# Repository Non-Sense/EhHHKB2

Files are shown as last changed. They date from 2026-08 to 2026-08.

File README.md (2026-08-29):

# EhHHKB2

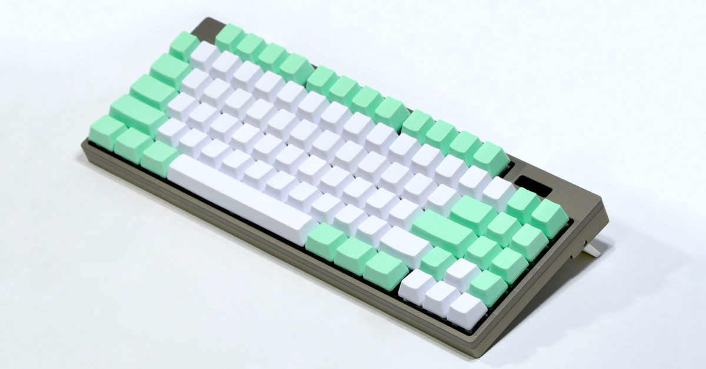
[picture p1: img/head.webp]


[ブログ記事](https://blog.n0n5ense.com/blog/DcFo77JwRCHzNenNpN4wraU0PMD/)

Raspberry Pi Pico 2 W（RP2350 + CYW43）を載せた自作キーボード。
85 キー（8×11 マトリクス / 6 行）、USB HID と BLE HID の両対応で、
BLE は6ホストを記憶して切り替えられる。128x32 OLED で状態表示と設定操作ができる。

## ディレクトリ

| ディレクトリ | 内容 |
| --- | --- |
| `board/` | KiCad 10 のプロジェクト一式（回路図・PCB・プロジェクト専用ライブラリ） |
| `case/` | ケースの 3D データ（STEP）とレンダー画像 |
| `firmware/` | Pico SDK ベースのファームウェア（C）、ホスト単体テスト、ドキュメント生成スクリプト |

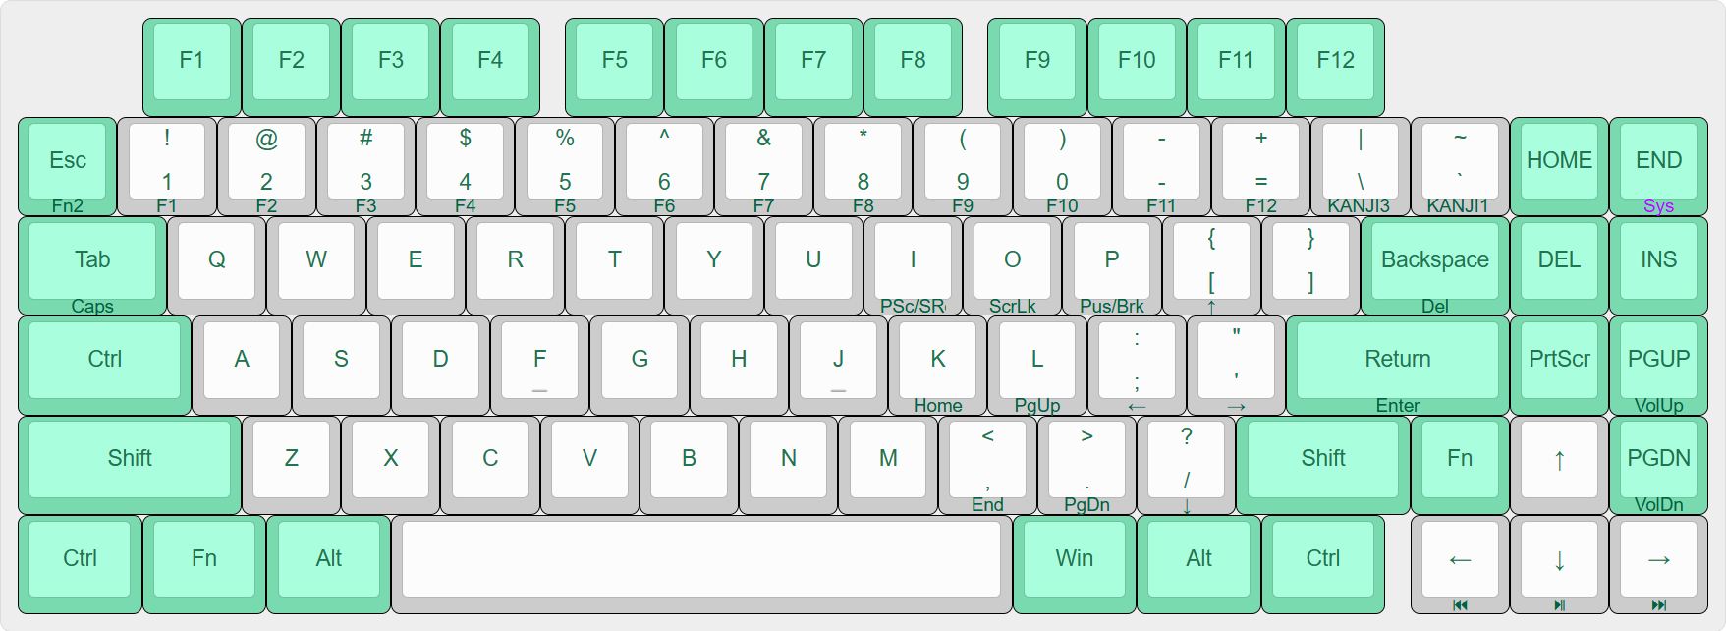
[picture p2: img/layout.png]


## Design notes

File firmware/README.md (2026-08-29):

# EhHHKB2 Firmware

Raspberry Pi Pico 2 W（RP2350 + CYW43）向けの自作キーボードファームウェア。
USB HID と BLE HID（HID over GATT）の両対応で、BLE は 6 ホストを記憶して切り替えられる。
128x32 の OLED に接続状態・バッテリー・LED インジケータを表示し、キーボードだけで設定変更ができる。

## 主な機能

- 8×11 キーマトリクス（88 交点のうち 85 キー）、0.5ms 周期スキャン・押下優先デバウンス
- 3 レイヤー（`_BASE` / `_FN` / `_FN2`）。押下した瞬間のキーコードをラッチするので、
  修飾を先に離してもキーが化けない
- 128bit bitmap レポートによる NKRO。ホストが Boot Protocol を要求したら 6KRO へ自動フォールバック
- Consumer Control による メディアキー（音量・再生・曲送り等）。USB / BLE 両対応
- BLE ホストスロット 6 個。ボンド・スロット名・Mac モードをフラッシュに永続化し、ホワイトリスト広告で切り替える
- スロットごとの Mac モード（`Ctrl` と `GUI(Win)` の usage を入れ替えて送信する）
- 出力先は「最後に接続が確立した方」のみ。USB と BLE へ同時送信はしない
- SSD1306 OLED への状態表示と、キーボードから操作するコンフィグメニュー
- バッテリー電圧の ADC 監視と、バッテリー駆動時の自動消灯

## ハードウェア

| 機能 | GPIO |
| --- | --- |
| キーマトリクス row（入力・プルアップ） | 2–9 |
| キーマトリクス col（出力・スキャン時のみ LOW） | 10–20 |
| OLED I2C0 SDA | 0 |
| OLED I2C0 SCL | 1 |
| USB センス（初期化のみ・未使用） | 22 |
| バッテリー電圧（ADC2 / 1/2 分圧） | 28 |

- ボード: `pico2_w`
- OLED: SSD1306 128x32、I2C アドレス `0x3C`、400kHz
- stdio（UART / USB CDC）は無効

## ビルド

Pico SDK 2.2.0 と arm toolchain 14_2_Rel1 を前提にしている（`~/.pico-sdk` 配下、または `PICO_SDK_PATH`）。

```powershell
cmake -S . -B build
cmake --build build
```

生成物は `build/ehhhkb2.uf2`。BOOTSEL を押しながら接続してドラッグ&ドロップするか、
コンフィグメニューの `Boot mode` から書き込みモードへ再起動できる。

### ホスト単体テスト

ハードウェアに触れないロジック（`ui/config_menu.c` と `hid/hid_report.c`）は PC 上で実行できる。

```powershell
cmake -S tests -B build-tests
cmake --build build-tests
ctest --test-dir build-tests --output-on-failure
```

### ドキュメント生成

`scripts/` に、OLED の全画面を実機と同じピクセル配置で PNG 化し、それを埋め込んだ
メニュー操作ガイド（`scripts/out/manual.html`、1 枚の自己完結 HTML）を組み立てる
スクリプトがある。`render_screens.py` は `display/ssd1306.c` の `font_data[]` と
`ui/screen.c` の描画ロジックを Python へ移植したものなので、**フォントや画面描画・
メニュー構成を変えたら両方を追従させて再生成する。**

```powershell
python -m venv scripts/.venv
scripts/.venv/Scripts/python.exe -m pip install -r scripts/requirements.txt
scripts/.venv/Scripts/python.exe scripts/render_screens.py   # scripts/out/*.png
scripts/.venv/Scripts/python.exe scripts/build_manual.py     # scripts/out/manual.html
```

## キーマップ

配列定義は `hid/key_matrix.c` の `keymap`、物理配列と行列の対応は `hid/key_matrix.h` の `LAYOUT` マクロ。

`_FN` は FN キー（右 Shift 隣 / 左下）の押下中、`_FN2` は FN + Esc の押下中に有効になる。
透過キーは `_FN2` → `_FN` → `_BASE` の順にフォールスルーする。

### `_FN`（FN 押下中）

| 押すキー | 出力 |
| --- | --- |
| `1`–`0` / `-` / `=` | F1–F10 / F11 / F12 |
| `` ` `` / `\` | Delete / Insert |
| `Tab` | CapsLock |
| `I` / `O` / `P` | PrintScreen / ScrollLock / Pause |
| `[` / `;` / `'` / `/` | ↑ / ← / → / ↓ |
| `K` / `,` / `L` / `.` | Home / End / PageUp / PageDown |
| `PageUp` / `PageDown` | 音量アップ / 音量ダウン（メディアキー） |
| `Esc` | `_FN2` レイヤーへ |

### `_FN2`（FN + Esc 押下中）

| 押すキー | 動作 |
| --- | --- |
| `1`–`6` | BLE スロット `BT1`–`BT6` へ接続を切り替える |
| `7` | BT を無効化して USB 専用にする |
| `Space` | ペアリング開始（オープン広告で新規デバイスを待つ）。ペアリング中に押すと離脱する |
| `Z` | 全スロットのボンドと名前を削除して待機 |
| `End` | コンフィグメニューを開く |

## BLE

- 広告名 `EhHHKB2` / Appearance `0x03C1`（キーボード） / HID Service `0x1812`
- ペアリングは Just Works（`IO_CAPABILITY_NO_INPUT_NO_OUTPUT`、Secure Connections + Bonding）
- Battery Service は実測電圧を Li-Po の放電曲線で 0–100% に換算して通知する。
  値が変わったときだけ、かつ 60 秒以上の間隔をおいて送る
- スロット番号は `le_device_db` のインデックスに直結する。上限は 6（`MAX_NR_LE_DEVICE_DB_ENTRIES` / `BLE_HOST_SLOTS`）
- スロット名（最大 10 文字）は BTstack の TLV フラッシュに保存される

### ホスト切り替えの挙動

対象スロットのボンドをホワイトリストに載せて広告することで、直前まで接続していたホスト OS の
即時再接続を弾いている。RPA を使うホストでも、コントローラのリゾルビングリストへ IRK を
読み込めていれば照合が通る。読み込めていない場合と、未ペアリングスロットへの切り替え時は
オープン広告へフォールバックする。

USB ホストとして enumerate した立ち上がりでは BT を自動的に OFF にする。
充電器のみの接続では発動しない。ケーブルを抜いても自動復帰はせず、`_FN2` の BT キーか
ペアリング操作で手動復帰する。

## コンフィグメニュー

`_FN2` + `End` で起動。↑↓ で移動、Enter で決定、Esc で戻る（トップで Esc なら終了）。
メニュー表示中は HID 送信を止め、押下中のキーはホストへ漏れない。

トップは 7 項目。接続に関係しない項目は `Misc` へまとめてある。

| 項目 | 内容 |
| --- | --- |
| `Connect` | `USB` / BT1–6 を選んで接続先を切り替える。取り消し線は未ペアリング、`(C)` が接続中 |
| `Pairing` | ペアリングモードへ入る（オープン広告で新規デバイスを待つ）。ペアリング中は `CancelPair` と表示され、選ぶと離脱する |
| `Mac mode` | スロットごとに Ctrl/GUI(Win) を入れ替えて送信する。行の右端が現在値（`ON` / `OFF`）で、決定しても画面は閉じない |
| `BLE rename` | スロット名を入力する。英数字・空白・`-`（Shift で `_`）、最大 10 文字 |
| `BLE swap` | 入れ替え元→入れ替え先の順にスロットを選び、ボンド・名前・Mac モードをまとめて入れ替える。入れ替え先画面では選択元に `(F)` を表示する。完了後も画面は閉じず、続けて別の組を入れ替えられる |
| `BLE reset` | スロットごとにボンドを削除する |
| `Misc` | 下記のサブメニューへ入る |

`Misc` の項目。`Battery` / `Boot mode` の画面から `Esc` で戻る先は `Misc`（それ以外の画面はトップへ戻る）。

| 項目 | 内容 |
| --- | --- |
| `Battery` | バッテリー電圧と残量 % を表示する |
| `Display Off` | ディスプレイを消灯する。消灯中もメニューを開けば表示は見え、項目は `Display On` に変わる。選び直すと点灯に戻る |
| `Quiet On` | CYW43 の `WL_GPIO1` を High にして内蔵 DC-DC を低ノイズ側へ固定する。有効中は `Quiet Off` と表示。効率は落ちるので電池持ちとのトレードオフ |
| `Boot mode` | BOOTSEL（UF2 書き込み）モードへ再起動する。破壊的操作なので末尾に置いている |

## ディスプレイ

- 上段: 接続先のスロット名（未設定なら `BT1`–`BT6`）/ `USB` / `PAIR` / `---`。
  右端はバッテリー残量アイコン、充電中は矢印と USB アイコン。
  接続中スロットが Mac モードなら残量アイコンの左に `M`
- 下段: ホストが通知した LED 状態を `NUM` / `CAP` / `SCR` で表示（USB / BLE どちらの
  接続でも Output レポートから取得する）。本機に物理 LED はない
- 残量アイコンのしきい値: `Battery` 画面や BLE 通知と同じ換算 % を参照する。75%以上で 5/5、
  50%以上で 4/5、25%以上で 2/5、未満は 0/5

点灯条件（`ui/display_policy.c`）は次のいずれか。

- 起動から 5 秒間
- コンフィグメニュー表示中
- USB 接続中
- `_FN2` レイヤーへ入った瞬間から 10 秒間（wakeup）
- ペアリングのコード表示中から、接続完了 +5 秒まで（後述のとおり Just Works では
  コードが出ないため、この条件は現状成立しない）

## 構成

| ディレクトリ | 役割 |
| --- | --- |
| `hid/` | マトリクススキャン、レイヤー解決、HID レポート組み立て、USB/BLE の出力振り分け |
| `usb/` | TinyUSB デバイススタックとディスクリプタ |
| `ble/` | BTstack による HID over GATT、ホストスロット管理、ボンド・名前の永続化 |
| `display/` | SSD1306 ドライバと 6x8 フォント |
| `power/` | バッテリー電圧の ADC サンプリング |
| `ui/` | コンフィグメニュー状態機械、点灯ポリシー、画面描画 |
| `tests/` | ホスト単体テスト |
| `scripts/` | OLED 画面プレビューとメニュー操作ガイドの生成（「ドキュメント生成」参照） |

### コア分担

- **Core 0**: キースキャン、TinyUSB、BTstack ポーリング、メニュー処理
- **Core 1**: バッテリー監視、OLED 描画

コア間で共有するのは `ui_state_t`（`ui/screen.h`）1 つだけで、critical section 経由で
まるごとスナップショットして受け渡す。Core 1 から BLE / USB / キーマトリクスの状態を
直接読みに行ってはならない。

`ui/config_menu.c` と `ui/display_policy.c` はハードウェアに触らない純粋な状態機械にしてある。
入力はキーレポートと状態のスナップショットだけで、副作用は `cfg_action_t` として呼び出し側へ返す。

### HID レポート形式

レポートは 2 種類あり、Report ID で区別する。

**Report ID 1: キーボード** — modifier 1 バイト + usage `0x00`–`0x7F` の 128bit bitmap（16 バイト）
+ 上位 usage 配列 2 バイト。

- USB: Report ID + 19 バイト
- BLE: Report ID は特性側（Report Reference）が持つので通知は 20 バイト。
  ディスクリプタが予約バイトを宣言しているため、modifier と bitmap の間に 1 バイト挿入する

bitmap は usage `0x7F` までしか表現できないため、`0x80` 以上は 8bit キーコードの配列
（`Report Size 8` / `Report Count 2`）で送る。JIS の `ろ`（`KC_KANJI1`）や `¥`（`KC_KANJI3`）が
これに該当する。同時押しは 2 キーまでで、溢れた分は捨てる。振り分けは
`hid_report_set_key()` が usage を見て自動で行うので、キーマップ側は区別しなくてよい。

BLE の 20 バイトはデフォルト ATT MTU 23 のペイロード上限と一致する。bitmap 自体を
256bit に拡張すると 34 バイトになり、MTU 拡張を negotiate しないホストで送信が
失敗するため、配列方式を選んでいる。

### レポート周期

USB はエンドポイントの `bInterval`（`usb/usb_descriptors.c` の `HID_POLL_INTERVAL_MS`）を
1 にしてあり、フルスピードでは 1ms ポーリング = 1000Hz になる。

キースキャンは `KEY_SCAN_INTERVAL_US`（`ehhhkb2.c`）で 0.5ms 周期。押下はデバウンス待ちが
無いため、押下遅延はスキャン待ち（最悪 0.5ms）+ USB ポーリング（最悪 1ms）で最悪 1.5ms・
平均 0.75ms。USB が 1ms 刻みなのでスキャンをこれ以上速くしても平均 0.125ms しか縮まらず、
フルスピード USB では `bInterval = 1` が構造的な下限になる。

離鍵は `KEY_DEBOUNCE_TICKS`（`hid/key_matrix.c`）ぶんの連続スキャンを待つ。**この値は
スキャン回数なので実時間はスキャン周期に比例する。** 0.5ms × 4 = 2ms で、メカニカル
スイッチのバウンス（1〜5ms）を吸収する下限に置いてある。スキャン周期を変えるときは
必ず両方を比例させること。片方だけ縮めると離鍵のチャタリングが漏れる。

BLE は `bInterval` と無関係で、接続インターバル（ホスト依存で 7.5〜30ms 程度）が
遅延を支配するため、スキャン周期を詰めても効果はない。

**Report ID 2: Consumer Control** — usage を 16bit の配列項目で 1 つ（2 バイト）。離鍵は 0 を送る。
レポートが 1 usage しか運べないため、メディアキーの同時押しは 1 つだけ有効になる。

ホストが Boot Protocol へ切り替えた場合（USB は `SET_PROTOCOL`、BLE は HIDS の Protocol Mode）は、
modifier + 予約 + キーコード 6 個の標準ブートレポートへ変換して送る。ブートプロトコルには
Report ID と Consumer Control が無いので、その間メディアキーは送らない。

### メディアキーの追加

`hid/keycode.h` の 16bit 仮想キーコードは範囲で用途を分けている。

| 範囲 | 用途 |
| --- | --- |
| `0x0000`–`0x00FF` | HID キーボード usage（キーボードレポートへ入れる） |
| `0x0100`–`0x0FFF` | ファームウェア内部のアクション（`KC_BT1` 等。HID へは出さない） |
| `0x1000`–`0x1FFF` | Consumer Control usage（`KC_MEDIA_BASE + usage`） |

定義済みは `KC_MPLAY` / `KC_MSTOP` / `KC_MPREV` / `KC_MNEXT` / `KC_MMUTE` / `KC_MVOLU` / `KC_MVOLD`。
他の usage を使いたい場合は `KC_MEDIA_BASE + 0x00XX` を足すだけでよく、レポート側の変更は不要
（ディスクリプタは usage `0x0000`–`0x03FF` を受け付ける）。

キーボードページの `KC_MUTE` / `KC_VOLUME_UP` / `KC_VOLUME_DOWN` は別物。メディアキーとして
使うなら `KC_M*` の方が確実。

### BLE の Report 特性

BTstack 同梱の `hids.gatt` は Input レポートを Report ID 1 の 1 本しか宣言しないため、
`ble/ehhhkb2.gatt` に自前の HID Service 宣言を置き、Consumer 用の 2 本目（Report ID 2, Input）を
足している。`hids_device_init_with_storage()` が宣言順に `REPORT_REFERENCE` を読んで
(id, type) を登録し、送信は `hids_device_send_input_report_for_id()` で ID を指定する。

Input が 2 本になるので、購読通知（`HIDS_SUBEVENT_INPUT_REPORT_ENABLE`）は report id で
振り分ける必要がある。振り分けないと Consumer の購読でキーボード側の送信可否を壊す。
`can_send_now` は 1 イベントにつき 1 通知しか送れないため、両方に変化があるときは
キーボードを先に送り、残りは次のループで再要求する。

## 既知の制限

- バッテリー残量は電圧からの換算なので、充電中は充電電圧を見てしまい実際より高く出る。
  充電状態を区別する仕組みは無い（OLED の残量アイコン・`Battery` 画面・BLE 通知はすべて
  同じ換算 % を参照するため、この誤差も含めて表示は一致する）
- USB センス（GPIO22）は初期化のみで読み出していない。USB 接続判定は
  `tud_mounted() && !tud_suspended()` で行う（自己給電では VBUS 検出が効かないため）
- ペアリング中に既知デバイスから接続要求が来た場合は切断して無視する。
  再ペアリングするには先にそのスロットを `BLE reset` する
- ペアリングは Just Works（`IO_CAPABILITY_NO_INPUT_NO_OUTPUT` / MITM 要求なし）なので、
  BTstack は `SM_EVENT_PASSKEY_DISPLAY_NUMBER` を上げない。`ui/screen.c` の
  `Code:######` 表示と、それを起点にする `ui/display_policy.c` のペアリング点灯
  ウィンドウは現状どちらも到達しない（ペアリング中の点灯は `_FN2` wakeup の 10 秒頼み）

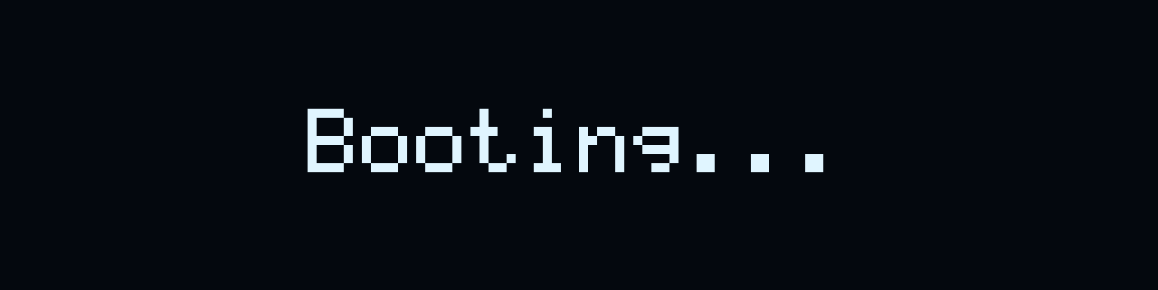
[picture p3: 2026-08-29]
firmware/scripts/out/22_booting.png

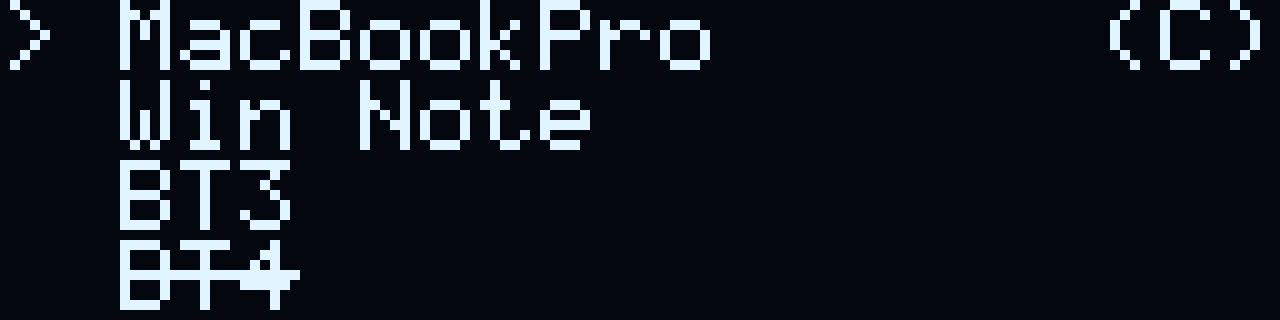
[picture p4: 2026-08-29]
firmware/scripts/out/16_menu_swap.png

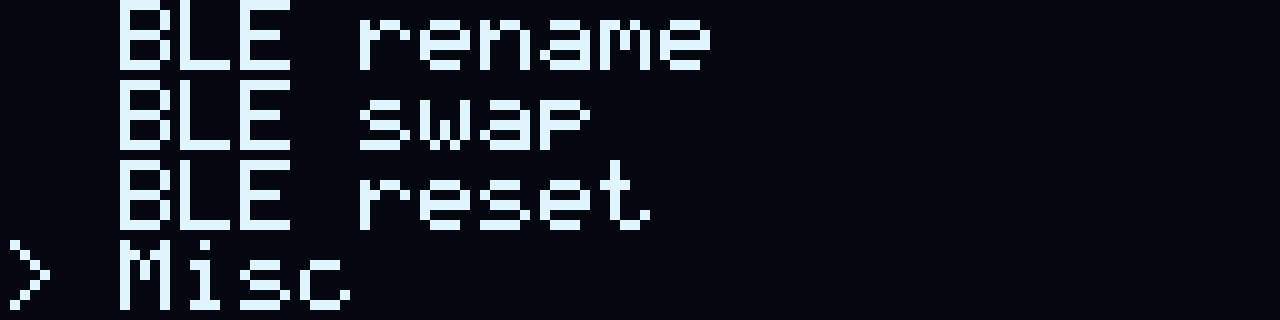
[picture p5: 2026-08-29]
firmware/scripts/out/11_menu_top_scrolled.png

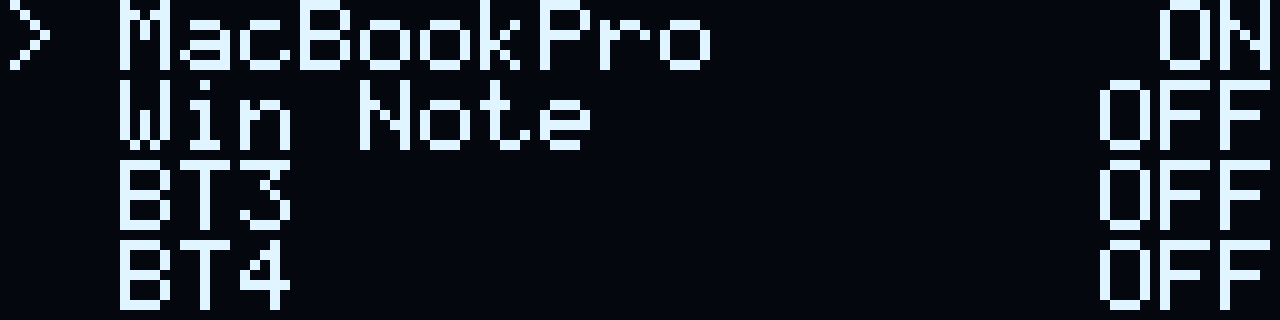
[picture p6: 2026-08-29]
firmware/scripts/out/13_menu_macmode.png

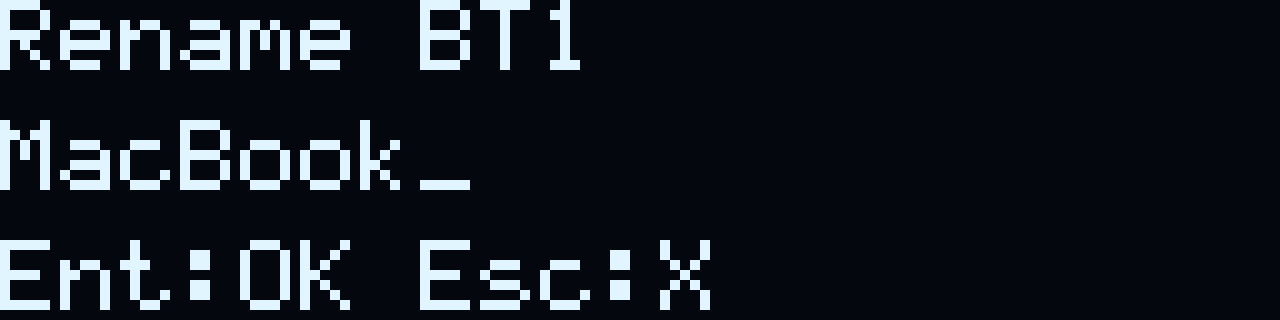
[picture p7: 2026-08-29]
firmware/scripts/out/15_menu_edit.png

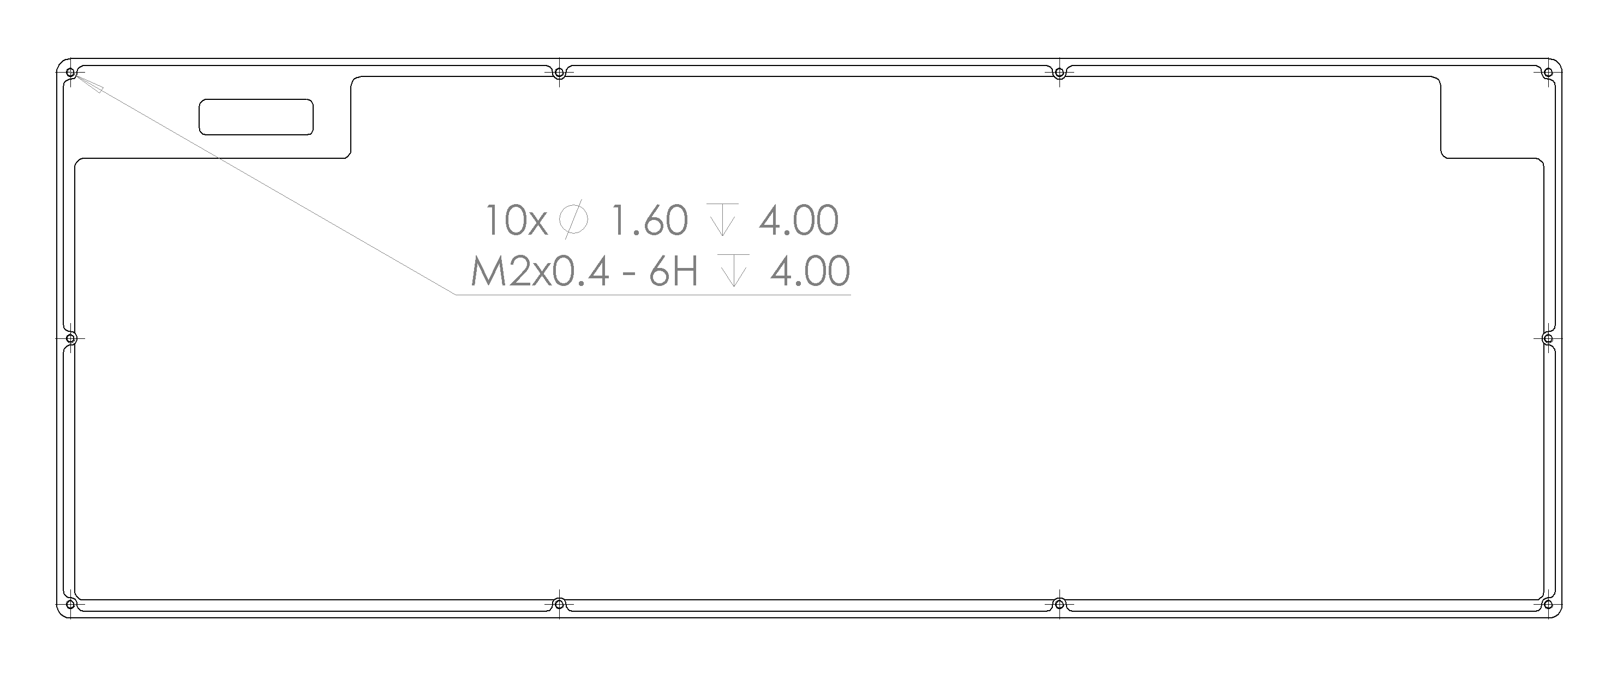
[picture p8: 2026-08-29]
case/top-case.png

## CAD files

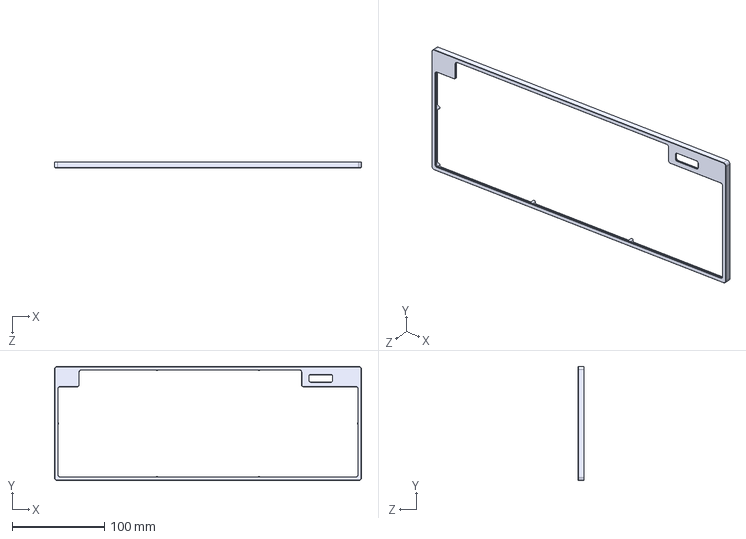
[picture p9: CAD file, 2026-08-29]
case/top-case.STEP
332.5 x 123.5 x 6.00 mm

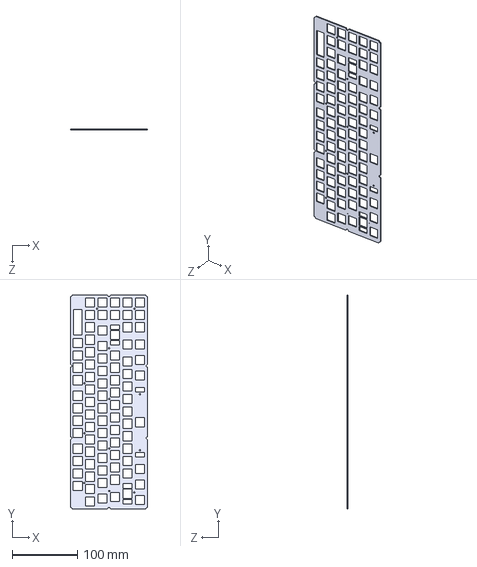
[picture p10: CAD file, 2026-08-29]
case/top-plate.STEP
118.5 x 327.5 x 1.50 mm

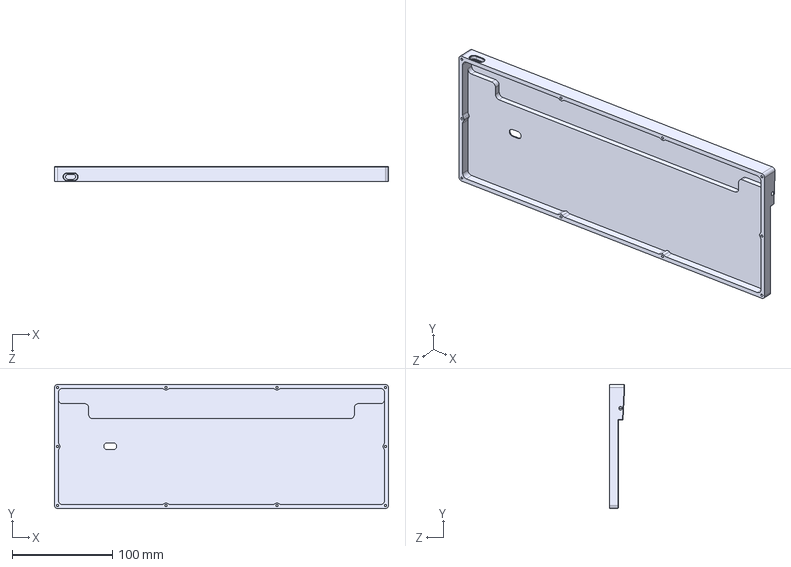
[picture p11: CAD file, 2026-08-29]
case/bottom-case.STEP
332.5 x 123.5 x 15.0 mm

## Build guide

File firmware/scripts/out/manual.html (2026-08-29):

# EhHHKB2 メニュー操作ガイド

128×32 の OLED に表示される全画面と、内蔵 6×8 ドットフォントの見え方を 実際のフォントデータから再現したプレビューでまとめたガイド。 キーボードだけで接続先の切り替え・ボンド管理・名前変更ができる。

ディスプレイ SSD1306 128×32 フォント 6×8（5×7 + 字間1px） メニュー起動 FN2 + End 表示行数 最大4行 BLEスロット 6

## 起動と基本操作

_FN2（FN+Esc 押下中）+ End でコンフィグメニューを開く。 メニュー表示中は HID 送信を止めるため、操作キーがホストに漏れることはない。

キー | 動作
↑ / ↓ | カーソルを移動する（末尾で反対側へループする）
Enter | 選択項目を決定する。名前入力画面ではその場で確定する
Esc | ひとつ前の画面へ戻る（Battery / Boot mode は Misc へ戻る）。トップメニューで押すとメニューを終了する
A–Z, 0–9, Space, - / _ | 名前入力画面でのみ有効。Backspace で1文字削除

### メニューを開かずに使うショートカット

よく使う操作は _FN2 レイヤーへ直接割り当ててある。

キー | 動作
_FN2 + 1–6 | BLE スロット BT1–BT6 へ接続を切り替える
_FN2 + 7 | BT を無効化して USB 専用にする
_FN2 + Space | ペアリング開始 / 中止
_FN2 + Z | 全スロットのボンドと名前を削除する
_FN2 + End | コンフィグメニューを開く

## ステータス画面

メニューを開いていないときの通常表示。上段に接続先、右端にバッテリー残量、 下段にホストから通知された Lock キーの状態を表示する。

BLE接続中（名前あり）

### BLE接続中（名前あり）

スロットに名前を付けている場合は BLE rename で設定した名前を表示する。右端はバッテリー残量アイコン（この例は満充電）。

BLE接続中（名前未設定）

### BLE接続中（名前未設定）

名前が空のスロットは BT1〜BT6 を表示する。基板の配線都合で内部のスロット番号とは逆順（内部スロット0が BT6、内部スロット5が BT1）だが、一覧は常に上から BT1→BT6 の昇順に並ぶ。

USB接続中

### USB接続中

BT を無効化して USB 専用にすると USB 表示になる。右端は USB アイコン（トライデント）と、その右に充電中を示す矢印。USB ホストとして認識された瞬間に BT は自動で OFF になる（充電器のみでは発動しない）。

ペアリング中

### ペアリング中

_FN2+Space（または Pairing メニュー）でオープン広告を始めると PAIR と表示する。ペアリングは Just Works なので、パスキーの表示・入力は無い（下記「既知の制限」を参照）。

未接続

### 未接続

BT 有効だがどのホストにも接続していない、かつペアリング中でもない状態。--- を表示する。

Macモード ON

### Macモード ON

接続中のスロットが Mac モードのときだけ、バッテリーアイコンの左に M を出す。Mac モード中は Ctrl と GUI(Win) の usage を入れ替えて送信する。

LEDインジケータ点灯

### LEDインジケータ点灯

ホストが通知した Lock 状態を下段に NUM / CAP / SCR の固定位置で表示する（消灯中の項目は描かれない）。本機に物理 LED は無い。USB・BLE どちらの接続でも Output レポートを受け取って反映する。

## 画面遷移

トップメニューから各機能画面への遷移。Esc は逆方向へ一段ずつ戻る。

点線の枠は、決定するとメニューを閉じて通常表示へ戻る項目。 Mac mode / BLE reset / 入れ替え先 は決定後も画面に留まるので、 続けて別のスロットを操作できる。

## 各画面の詳細

トップメニューの7項目と、その先の子画面。取り消し線・(C)・(F)・ カーソルの>は実機の描画ロジックをそのまま再現している。

トップメニュー

### トップメニュー

FN2+End で起動

_FN2+End で開く最初の画面。↑/↓ で > カーソルを動かし、Enter で決定する。7 項目あるが 1 画面は 4 行なので、入りきらない分はカーソルに追従してスクロールする。

- Connect — 接続先の切り替え
- Pairing — ペアリングの開始 / 中止
- Mac mode — スロットごとの Ctrl/GUI 入れ替え
- BLE rename — スロット名の変更
- BLE swap — スロットの中身の入れ替え
- BLE reset — ボンドの削除
- Misc — Battery / Display / Quiet / Boot mode

トップメニュー（スクロール後）

### トップメニュー（スクロール後）

↓ で下端へ

カーソルが表示窓の下端に達すると 1 行ずつ送られる（窓の先頭はカーソルの 1 つ上に張り付く）。カーソルは末尾で反対側へループするので、開いた直後に ↑ を 1 回押すだけでも最下段の Misc に届く。

Connect（接続先選択）

### Connect（接続先選択）

Enter で切替

先頭が USB、続いて BT1〜BT6。取り消し線はボンドが無い（未ペアリング）スロット、右端の (C) は現在の接続先を示す。取り消し線のスロットと接続中のスロットは選んでも何も起きない。切り替えを決定するとメニューは閉じる。

Mac mode（スロットごと）

### Mac mode（スロットごと）

Enter でトグル

行の右端の ON / OFF が現在値。Enter で切り替えても画面は開いたままなので、続けて他のスロットも変更できる。値はスロットごとにフラッシュへ保存される。

BLE rename（スロット選択）

### BLE rename（スロット選択）

Enter で編集へ

名前を変更するスロットを選ぶ。名前が設定済みのスロットは BT1 MacBookPro のように現在の名前を添えて表示する。

名前入力

### 名前入力

Enter:確定 Esc:戻る

英数字・空白・-（Shift で _）を最大 10 文字入力できる。末尾の _ は入力カーソル、Backspace で 1 文字削除する。Enter で確定して一覧へ戻り、Esc は保存せずに一覧へ戻る。空のまま確定すると名前を削除する。

BLE swap（入れ替え元）

### BLE swap（入れ替え元）

Enter で次へ

スロットの中身（ボンド・名前・Mac モード）をまるごと入れ替える機能。まず入れ替え元を選ぶ。表示は BLE reset と同じで、取り消し線が未ペアリング、(C) が接続中。

BLE swap（入れ替え先）

### BLE swap（入れ替え先）

Enter で実行

入れ替え元のスロットには (F) が付く。別のスロットを選ぶとその場で入れ替え、入れ替え元の選択へ戻る（続けて別の組も入れ替えられる）。どちらかに接続中だった場合は切断される。

BLE reset（ボンド削除）

### BLE reset（ボンド削除）

Enter で削除

スロットを選んで Enter を押すとそのボンドを削除する（確認画面は無い）。取り消し線はすでに未ペアリングであることを示す。画面は閉じないので、続けて他のスロットも消せる。

Misc

### Misc

Esc で Top へ

接続に関係しない項目をまとめた画面。Display と Quiet は現在値でラベルが入れ替わる（消灯中は Display On、Quiet 有効中は Quiet Off）。どちらも選ぶとメニューを閉じる。

- Battery — 電圧と残量の表示
- Display Off / On — 手動消灯の切り替え
- Quiet On / Off — 内蔵 DC-DC を低ノイズ側へ固定
- Boot mode — 書き込みモードへ再起動

Battery（電圧表示）

### Battery（電圧表示）

Esc で Misc へ

実測電圧とバッテリー残量の概算 % を表示するだけの画面（リストではない）。充電中は充電電圧を見てしまうため実際より高く出る点に注意。

Boot mode（確認）

### Boot mode（確認）

Enter:実行 Esc:キャンセル

Enter で BOOTSEL（UF2 書き込み）モードへ即座に再起動する。破壊的操作のため Misc の最後尾に置かれている。

再起動直前

### 再起動直前

ブートローダへ落ちる直前に Booting... を中央表示する。省電力でパネルが消えていても見えるよう、この間だけ点灯を強制する。

## アイコンとマーカー

右上に表示されるインジケータ用グリフ。ASCII 印字可能文字（0x20–0x7E）の続きに 独自グリフを追加している。

5/5 75% 以上

4/5 50% 以上

2/5 25% 以上

0/5 25% 未満

充電中 USB 接続中に右端へ表示する矢印アイコン

USB USB 接続中に表示するトライデント（矢印の左隣）

表示 | 場所 | 意味
> | 一覧画面の左端 | カーソル位置。↑/↓ で動かす
(C) | Connect / BLE reset / BLE swap | 現在接続しているスロット
(F) | BLE swap（入れ替え先） | 先に選んだ入れ替え元のスロット
ON / OFF | Mac mode | そのスロットの Mac モードの現在値
取り消し線 | Connect / BLE reset / BLE swap | ボンドが無い（未ペアリング）スロット
M | ステータス画面の右上 | 接続中スロットが Mac モード
_ | 名前入力 | 文字入力カーソル

## 内蔵フォント

display/ssd1306.c の font_data[] 全 103 文字（0x20–0x86）。 1 文字は 5×7 ドット + 字間 1px の 6×8 で、1 行は最大 21 文字・1 画面は 4 行。 0x7F（BTマーク）と 0x80（✕印）はフォントには入っているが、 現在の画面描画では使っていない。

6x8 フォント一覧

## 既知の制限

- バッテリー残量は電圧からの概算 — 充電中は充電電圧を見てしまうため、実際より高く表示される。 残量アイコン・Battery画面・BLE通知はすべて同じ換算 % を参照するため、この誤差も含めて表示は一致する
- ペアリング中に既知デバイスから接続要求が来たら無視する — 切断して待機を続けるため、 同じホストと再ペアリングするには先にそのスロットを BLE reset する
- ペアリング中にパスキーは表示されない — ble/ble_hid.c が IO_CAPABILITY_NO_INPUT_NO_OUTPUT（MITM 要求なし）で初期化するため、 ペアリングは常に Just Works になる。ui/screen.c には Code:###### を描く経路があるが、現在の設定では到達しない
- Quiet mode は電池持ちとのトレードオフ — 内蔵 DC-DC を低ノイズ側へ固定するため、 軽負荷時の効率が落ちる。ノイズが気になる場面だけ有効にする
- 表示できる文字数の上限 — 1 行 21 文字・4 行まで。スロット名は 10 文字までで、 それを超える入力は受け付けない

display/ssd1306.c の font_data[] と ui/screen.c の描画ロジックから生成したプレビュー

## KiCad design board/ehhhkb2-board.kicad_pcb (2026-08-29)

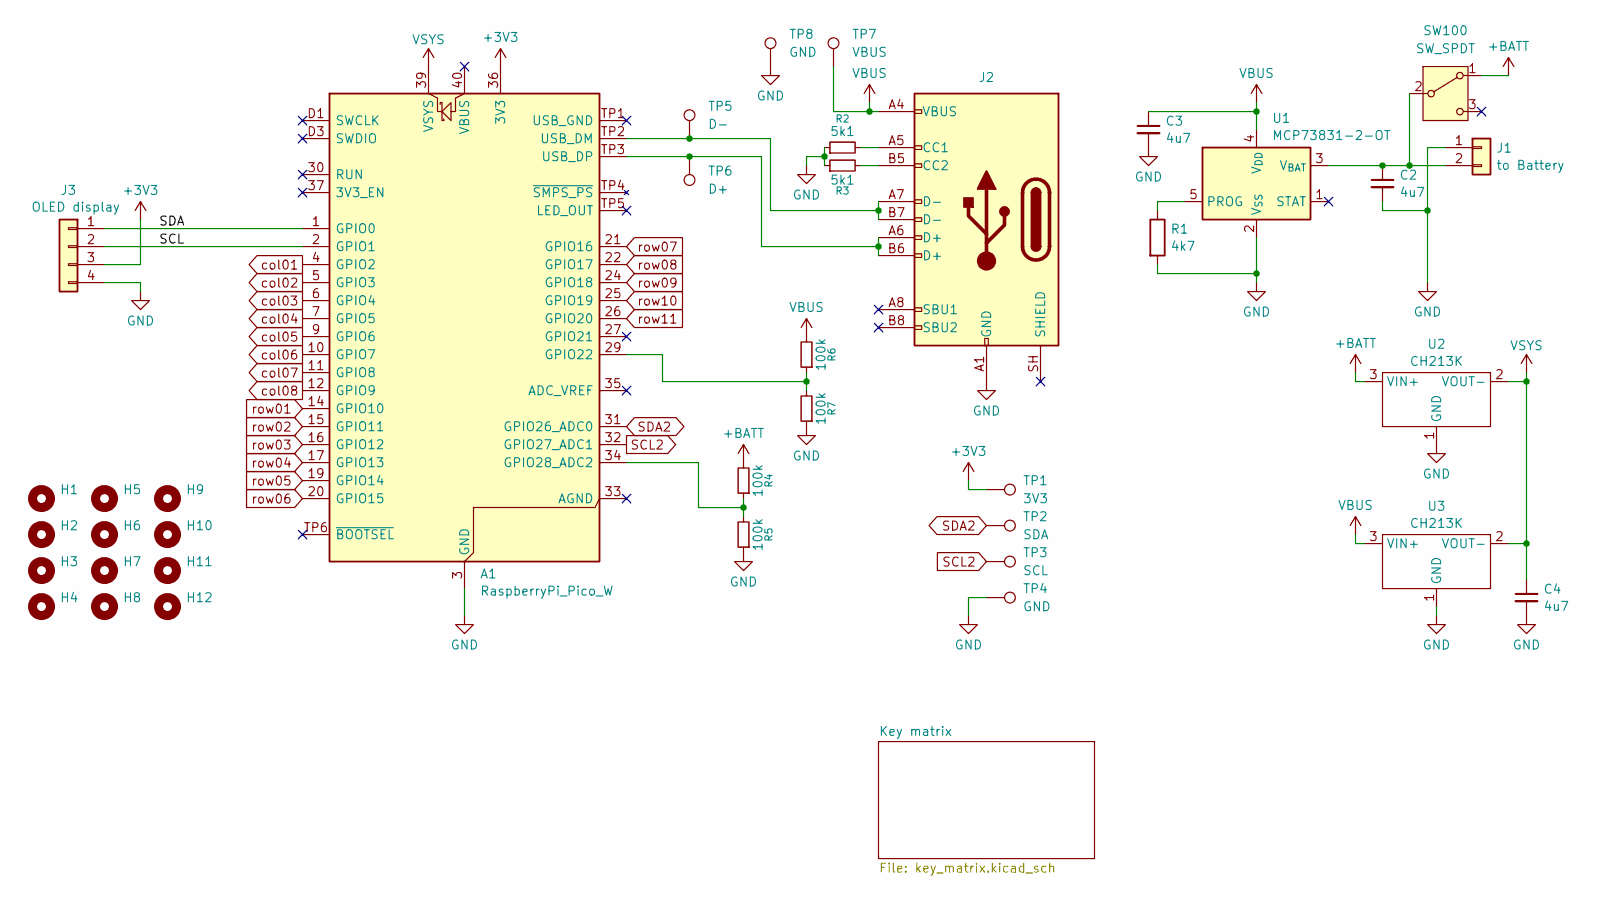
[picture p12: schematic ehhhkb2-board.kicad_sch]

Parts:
A1: RaspberryPi_Pico_W; RPi_Pico_SMD_Pins_No_SWD_No_Text
C2, C3, C4: 4u7; C_0603_1608Metric
H1, H2, H3, H4, H5, H6, H7, H8, H9, H10, H11, H12: MountingHole; MountingHole_2.2mm_M2
J1: to Battery; JST_PH_S2B-PH-K_1x02_P2.00mm_Horizontal
J2: USB_C_Receptacle_USB2.0_16P; 5077CR-16-SMC2
J3: OLED display; PinSocket_1x04_P2.54mm_Vertical
R1: 4k7; R_0603_1608Metric
R2, R3: 5k1; R_0603_1608Metric
R4, R5, R6, R7: 100k; R_0603_1608Metric
SW100: SW_SPDT; SW_Slide-03_Wuerth-WS-SLTV_10x2.5x6.4_P2.54mm
TP1: 3V3; TestPoint-0.75mm
TP2: SDA; TestPoint-0.75mm
TP3: SCL; TestPoint-0.75mm
TP4: GND; TestPoint-0.75mm
TP5: D-; TestPoint_Pad_D1.5mm
TP6: D+; TestPoint_Pad_D1.5mm
TP7: VBUS; TestPoint_Pad_D1.5mm
TP8: GND; TestPoint_Pad_D1.5mm
U1: MCP73831-2-OT; SOT-23-5
U2, U3: CH213K; SOT-23

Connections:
+3V3: A1.36 (3V3), J3.3, TP1.1 (1_1)
+BATT: R4.2, SW100.1 (A), U2.3 (VI+)
/SCL: A1.2 (GPIO1), J3.2
/SDA: A1.1 (GPIO0), J3.1
GND: A1.3 (GND), A1.8 (GND), A1.13 (GND), A1.18 (GND), A1.23 (GND), A1.28 (GND), A1.38 (GND), A1.D2 (GND), C2.2, C3.2, C4.2, J1.1, J2.A1 (GND), J2.A12 (GND), J2.B1 (GND), J2.B12 (GND), J3.4, R1.2, R2.1, R3.1, R5.1, R7.1, TP4.1 (1_1), TP8.1 (1_1), U1.2 (V_{SS}), U2.1 (GND), U3.1 (GND)
unnamed: A1.29 (GPIO22), R6.1, R7.2
unnamed: A1.34 (GPIO28_ADC2), R4.1, R5.2
unnamed: A1.TP2 (USB_DM), J2.A7 (D-), J2.B7 (D-), TP5.1 (1_1)
unnamed: A1.TP3 (USB_DP), J2.A6 (D+), J2.B6 (D+), TP6.1 (1_1)
unnamed: C2.1, J1.2, SW100.2 (B), U1.3 (V_{BAT})
unnamed: J2.A5 (CC1), R2.2
unnamed: J2.B5 (CC2), R3.2
unnamed: R1.1, U1.5 (PROG)
SCL2: A1.32 (GPIO27_ADC1), TP3.1 (1_1)
SDA2: A1.31 (GPIO26_ADC0), TP2.1 (1_1)
VBUS: C3.1, J2.A4 (VBUS), J2.A9 (VBUS), J2.B4 (VBUS), J2.B9 (VBUS), R6.2, TP7.1 (1_1), U1.4 (V_{DD}), U3.3 (VI+)
VSYS: A1.39 (VSYS), C4.1, U2.2 (VO-), U3.2 (VO-)
col01: A1.4 (GPIO2); also elsewhere on the board
col02: A1.5 (GPIO3); also elsewhere on the board
col03: A1.6 (GPIO4); also elsewhere on the board
col04: A1.7 (GPIO5); also elsewhere on the board
col05: A1.9 (GPIO6); also elsewhere on the board
col06: A1.10 (GPIO7); also elsewhere on the board
col07: A1.11 (GPIO8); also elsewhere on the board
col08: A1.12 (GPIO9); also elsewhere on the board
row01: A1.14 (GPIO10); also elsewhere on the board
row02: A1.15 (GPIO11); also elsewhere on the board
row03: A1.16 (GPIO12); also elsewhere on the board
row04: A1.17 (GPIO13); also elsewhere on the board
row05: A1.19 (GPIO14); also elsewhere on the board
row06: A1.20 (GPIO15); also elsewhere on the board
row07: A1.21 (GPIO16); also elsewhere on the board
row08: A1.22 (GPIO17); also elsewhere on the board
row09: A1.24 (GPIO18); also elsewhere on the board
row10: A1.25 (GPIO19); also elsewhere on the board
row11: A1.26 (GPIO20); also elsewhere on the board

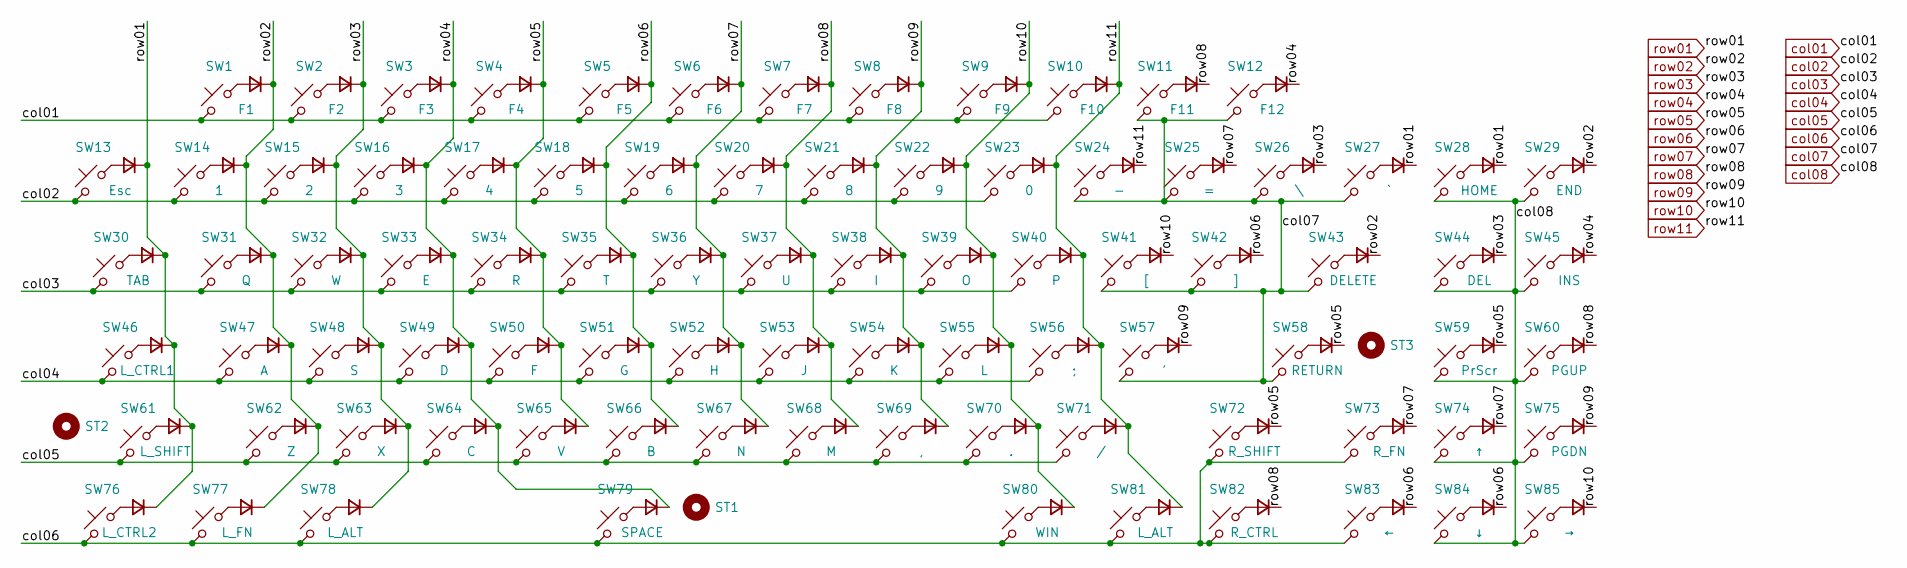
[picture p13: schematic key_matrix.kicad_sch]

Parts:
D1, D2, D3, D4, D5, D6, D7, D8, D9, D10, D11, D12, D13, D14, D15, D16, D17, D18, D19, D20, D21, D22, D23, D24, D25, D26, D27, D28, D29, D30, D31, D32, D33, D34, D35, D36, D37, D38, D39, D40, D41, D42, D43, D44, D45, D46, D47, D48, D49, D50, D51, D52, D53, D54, D55, D56, D57, D58, D59, D60, D61, D62, D63, D64, D65, D66, D67, D68, D69, D70, D71, D72, D73, D74, D75, D76, D77, D78, D79, D80, D81, D82, D83, D84, D85: D; D_SOD-123
ST1: Stabilizer_Cherry_MX_6.25u
ST2, ST3: Stabilizer_Cherry_MX_2.00u
SW1: F1; SW_Hotswap_Kailh_MX_1.00u
SW2: F2; SW_Hotswap_Kailh_MX_1.00u
SW3: F3; SW_Hotswap_Kailh_MX_1.00u
SW4: F4; SW_Hotswap_Kailh_MX_1.00u
SW5: F5; SW_Hotswap_Kailh_MX_1.00u
SW6: F6; SW_Hotswap_Kailh_MX_1.00u
SW7: F7; SW_Hotswap_Kailh_MX_1.00u
SW8: F8; SW_Hotswap_Kailh_MX_1.00u
SW9: F9; SW_Hotswap_Kailh_MX_1.00u
SW10: F10; SW_Hotswap_Kailh_MX_1.00u
SW11: F11; SW_Hotswap_Kailh_MX_1.00u
SW12: F12; SW_Hotswap_Kailh_MX_1.00u
SW13: Esc; SW_Hotswap_Kailh_MX_1.00u
SW14: 1; SW_Hotswap_Kailh_MX_1.00u
SW15: 2; SW_Hotswap_Kailh_MX_1.00u
SW16: 3; SW_Hotswap_Kailh_MX_1.00u
SW17: 4; SW_Hotswap_Kailh_MX_1.00u
SW18: 5; SW_Hotswap_Kailh_MX_1.00u
SW19: 6; SW_Hotswap_Kailh_MX_1.00u
SW20: 7; SW_Hotswap_Kailh_MX_1.00u
SW21: 8; SW_Hotswap_Kailh_MX_1.00u
SW22: 9; SW_Hotswap_Kailh_MX_1.00u
SW23: 0; SW_Hotswap_Kailh_MX_1.00u
SW24: -; SW_Hotswap_Kailh_MX_1.00u
SW25: =; SW_Hotswap_Kailh_MX_1.00u
SW26: \; SW_Hotswap_Kailh_MX_1.00u
SW27: `; SW_Hotswap_Kailh_MX_1.00u
SW28: HOME; SW_Hotswap_Kailh_MX_1.00u
SW29: END; SW_Hotswap_Kailh_MX_1.00u
SW30: TAB; SW_Hotswap_Kailh_MX_1.50u
SW31: Q; SW_Hotswap_Kailh_MX_1.00u
SW32: W; SW_Hotswap_Kailh_MX_1.00u
SW33: E; SW_Hotswap_Kailh_MX_1.00u
SW34: R; SW_Hotswap_Kailh_MX_1.00u
SW35: T; SW_Hotswap_Kailh_MX_1.00u
SW36: Y; SW_Hotswap_Kailh_MX_1.00u
SW37: U; SW_Hotswap_Kailh_MX_1.00u
SW38: I; SW_Hotswap_Kailh_MX_1.00u
SW39: O; SW_Hotswap_Kailh_MX_1.00u
SW40: P; SW_Hotswap_Kailh_MX_1.00u
SW41: [; SW_Hotswap_Kailh_MX_1.00u
SW42: ]; SW_Hotswap_Kailh_MX_1.00u
SW43: DELETE; SW_Hotswap_Kailh_MX_1.50u
SW44: DEL; SW_Hotswap_Kailh_MX_1.00u
SW45: INS; SW_Hotswap_Kailh_MX_1.00u
SW46: L_CTRL1; SW_Hotswap_Kailh_MX_1.75u
SW47: A; SW_Hotswap_Kailh_MX_1.00u
SW48: S; SW_Hotswap_Kailh_MX_1.00u
SW49: D; SW_Hotswap_Kailh_MX_1.00u
SW50: F; SW_Hotswap_Kailh_MX_1.00u
SW51: G; SW_Hotswap_Kailh_MX_1.00u
SW52: H; SW_Hotswap_Kailh_MX_1.00u
SW53: J; SW_Hotswap_Kailh_MX_1.00u
SW54: K; SW_Hotswap_Kailh_MX_1.00u
SW55: L; SW_Hotswap_Kailh_MX_1.00u
SW56: ;; SW_Hotswap_Kailh_MX_1.00u
SW57: '; SW_Hotswap_Kailh_MX_1.00u
SW58: RETURN; SW_Hotswap_Kailh_MX_2.25u
SW59: PrScr; SW_Hotswap_Kailh_MX_1.00u
SW60: PGUP; SW_Hotswap_Kailh_MX_1.00u
SW61: L_SHIFT; SW_Hotswap_Kailh_MX_2.25u
SW62: Z; SW_Hotswap_Kailh_MX_1.00u
SW63: X; SW_Hotswap_Kailh_MX_1.00u
SW64: C; SW_Hotswap_Kailh_MX_1.00u
SW65: V; SW_Hotswap_Kailh_MX_1.00u
SW66: B; SW_Hotswap_Kailh_MX_1.00u
SW67: N; SW_Hotswap_Kailh_MX_1.00u
SW68: M; SW_Hotswap_Kailh_MX_1.00u
SW69: ,; SW_Hotswap_Kailh_MX_1.00u
SW70: .; SW_Hotswap_Kailh_MX_1.00u
SW71: /; SW_Hotswap_Kailh_MX_1.00u
SW72: R_SHIFT; SW_Hotswap_Kailh_MX_1.75u
SW73: R_FN; SW_Hotswap_Kailh_MX_1.00u
SW74: ↑; SW_Hotswap_Kailh_MX_1.00u
SW75: PGDN; SW_Hotswap_Kailh_MX_1.00u
SW76: L_CTRL2; SW_Hotswap_Kailh_MX_1.25u
SW77: L_FN; SW_Hotswap_Kailh_MX_1.25u
SW78, SW81: L_ALT; SW_Hotswap_Kailh_MX_1.25u
SW79: SPACE; SW_Hotswap_Kailh_MX_6.25u
SW80: WIN; SW_Hotswap_Kailh_MX_1.25u
SW82: R_CTRL; SW_Hotswap_Kailh_MX_1.25u
SW83: ←; SW_Hotswap_Kailh_MX_1.00u
SW84: ↓; SW_Hotswap_Kailh_MX_1.00u
SW85: →; SW_Hotswap_Kailh_MX_1.00u

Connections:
unnamed: D1.2 (A), SW1.1
unnamed: D2.2 (A), SW2.1
unnamed: D3.2 (A), SW3.1
unnamed: D4.2 (A), SW4.1
unnamed: D5.2 (A), SW5.1
unnamed: D6.2 (A), SW6.1
unnamed: D7.2 (A), SW7.1
unnamed: D8.2 (A), SW8.1
unnamed: D9.2 (A), SW9.1
unnamed: D10.2 (A), SW10.1
unnamed: D11.2 (A), SW11.1
unnamed: D12.2 (A), SW12.1
unnamed: D13.2 (A), SW13.1
unnamed: D14.2 (A), SW14.1
unnamed: D15.2 (A), SW15.1
unnamed: D16.2 (A), SW16.1
unnamed: D17.2 (A), SW17.1
unnamed: D18.2 (A), SW18.1
unnamed: D19.2 (A), SW19.1
unnamed: D20.2 (A), SW20.1
unnamed: D21.2 (A), SW21.1
unnamed: D22.2 (A), SW22.1
unnamed: D23.2 (A), SW23.1
unnamed: D24.2 (A), SW24.1
unnamed: D25.2 (A), SW25.1
unnamed: D26.2 (A), SW26.1
unnamed: D27.2 (A), SW27.1
unnamed: D28.2 (A), SW28.1
unnamed: D29.2 (A), SW29.1
unnamed: D30.2 (A), SW30.1
unnamed: D31.2 (A), SW31.1
unnamed: D32.2 (A), SW32.1
unnamed: D33.2 (A), SW33.1
unnamed: D34.2 (A), SW34.1
unnamed: D35.2 (A), SW35.1
unnamed: D36.2 (A), SW36.1
unnamed: D37.2 (A), SW37.1
unnamed: D38.2 (A), SW38.1
unnamed: D39.2 (A), SW39.1
unnamed: D40.2 (A), SW40.1
unnamed: D41.2 (A), SW41.1
unnamed: D42.2 (A), SW42.1
unnamed: D43.2 (A), SW43.1
unnamed: D44.2 (A), SW44.1
unnamed: D45.2 (A), SW45.1
unnamed: D46.2 (A), SW46.1
unnamed: D47.2 (A), SW47.1
unnamed: D48.2 (A), SW48.1
unnamed: D49.2 (A), SW49.1
unnamed: D50.2 (A), SW50.1
unnamed: D51.2 (A), SW51.1
unnamed: D52.2 (A), SW52.1
unnamed: D53.2 (A), SW53.1
unnamed: D54.2 (A), SW54.1
unnamed: D55.2 (A), SW55.1
unnamed: D56.2 (A), SW56.1
unnamed: D57.2 (A), SW57.1
unnamed: D58.2 (A), SW58.1
unnamed: D59.2 (A), SW59.1
unnamed: D60.2 (A), SW60.1
unnamed: D61.2 (A), SW61.1
unnamed: D62.2 (A), SW62.1
unnamed: D63.2 (A), SW63.1
unnamed: D64.2 (A), SW64.1
unnamed: D65.2 (A), SW65.1
unnamed: D66.2 (A), SW66.1
unnamed: D67.2 (A), SW67.1
unnamed: D68.2 (A), SW68.1
unnamed: D69.2 (A), SW69.1
unnamed: D70.2 (A), SW70.1
unnamed: D71.2 (A), SW71.1
unnamed: D72.2 (A), SW72.1
unnamed: D73.2 (A), SW73.1
unnamed: D74.2 (A), SW74.1
unnamed: D75.2 (A), SW75.1
unnamed: D76.2 (A), SW76.1
unnamed: D77.2 (A), SW77.1
unnamed: D78.2 (A), SW78.1
unnamed: D79.2 (A), SW79.1
unnamed: D80.2 (A), SW80.1
unnamed: D81.2 (A), SW81.1
unnamed: D82.2 (A), SW82.1
unnamed: D83.2 (A), SW83.1
unnamed: D84.2 (A), SW84.1
unnamed: D85.2 (A), SW85.1
col01: SW1.2, SW2.2, SW3.2, SW4.2, SW5.2, SW6.2, SW7.2, SW8.2, SW9.2, SW10.2; also elsewhere on the board
col02: SW13.2, SW14.2, SW15.2, SW16.2, SW17.2, SW18.2, SW19.2, SW20.2, SW21.2, SW22.2, SW23.2; also elsewhere on the board
col03: SW30.2, SW31.2, SW32.2, SW33.2, SW34.2, SW35.2, SW36.2, SW37.2, SW38.2, SW39.2, SW40.2; also elsewhere on the board
col04: SW46.2, SW47.2, SW48.2, SW49.2, SW50.2, SW51.2, SW52.2, SW53.2, SW54.2, SW55.2, SW56.2; also elsewhere on the board
col05: SW61.2, SW62.2, SW63.2, SW64.2, SW65.2, SW66.2, SW67.2, SW68.2, SW69.2, SW70.2, SW71.2; also elsewhere on the board
col06: SW72.2, SW73.2, SW76.2, SW77.2, SW78.2, SW79.2, SW80.2, SW81.2, SW82.2, SW83.2; also elsewhere on the board
col07: SW11.2, SW12.2, SW24.2, SW25.2, SW26.2, SW27.2, SW41.2, SW42.2, SW43.2, SW57.2, SW58.2; also elsewhere on the board
col08: SW28.2, SW29.2, SW44.2, SW45.2, SW59.2, SW60.2, SW74.2, SW75.2, SW84.2, SW85.2; also elsewhere on the board
row01: D13.1 (K), D27.1 (K), D28.1 (K), D30.1 (K), D46.1 (K), D61.1 (K), D76.1 (K); also elsewhere on the board
row02: D1.1 (K), D14.1 (K), D29.1 (K), D31.1 (K), D43.1 (K), D47.1 (K), D62.1 (K), D77.1 (K); also elsewhere on the board
row03: D2.1 (K), D15.1 (K), D26.1 (K), D32.1 (K), D44.1 (K), D48.1 (K), D63.1 (K), D78.1 (K); also elsewhere on the board
row04: D3.1 (K), D12.1 (K), D16.1 (K), D33.1 (K), D45.1 (K), D49.1 (K), D64.1 (K), D79.1 (K); also elsewhere on the board
row05: D4.1 (K), D17.1 (K), D34.1 (K), D50.1 (K), D58.1 (K), D59.1 (K), D65.1 (K), D72.1 (K); also elsewhere on the board
row06: D5.1 (K), D18.1 (K), D35.1 (K), D42.1 (K), D51.1 (K), D66.1 (K), D83.1 (K), D84.1 (K); also elsewhere on the board
row07: D6.1 (K), D19.1 (K), D25.1 (K), D36.1 (K), D52.1 (K), D67.1 (K), D73.1 (K), D74.1 (K); also elsewhere on the board
row08: D7.1 (K), D11.1 (K), D20.1 (K), D37.1 (K), D53.1 (K), D60.1 (K), D68.1 (K), D82.1 (K); also elsewhere on the board
row09: D8.1 (K), D21.1 (K), D38.1 (K), D54.1 (K), D57.1 (K), D69.1 (K), D75.1 (K); also elsewhere on the board
row10: D9.1 (K), D22.1 (K), D39.1 (K), D41.1 (K), D55.1 (K), D70.1 (K), D80.1 (K), D85.1 (K); also elsewhere on the board
row11: D10.1 (K), D23.1 (K), D24.1 (K), D40.1 (K), D56.1 (K), D71.1 (K), D81.1 (K); also elsewhere on the board

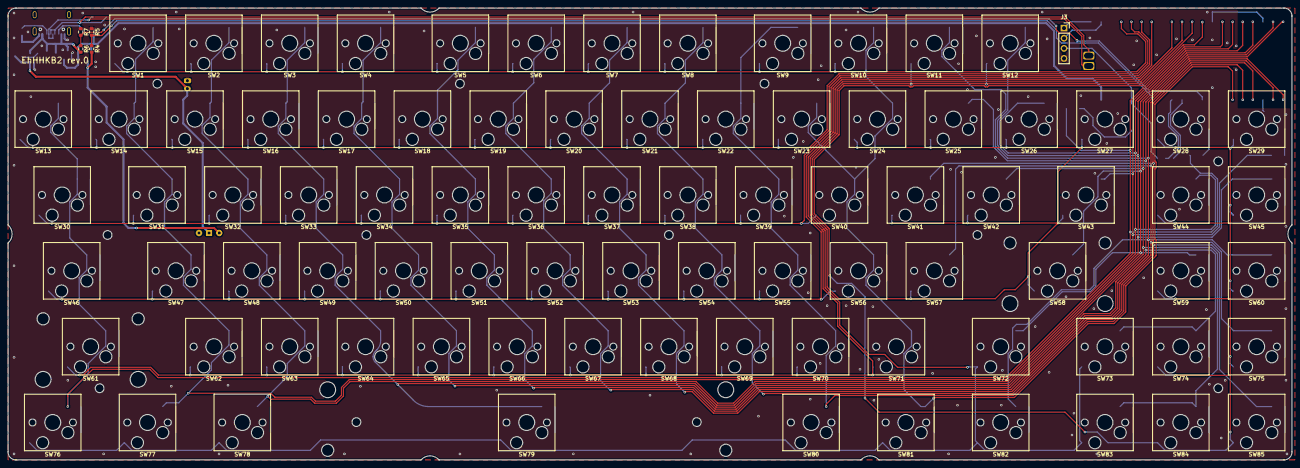
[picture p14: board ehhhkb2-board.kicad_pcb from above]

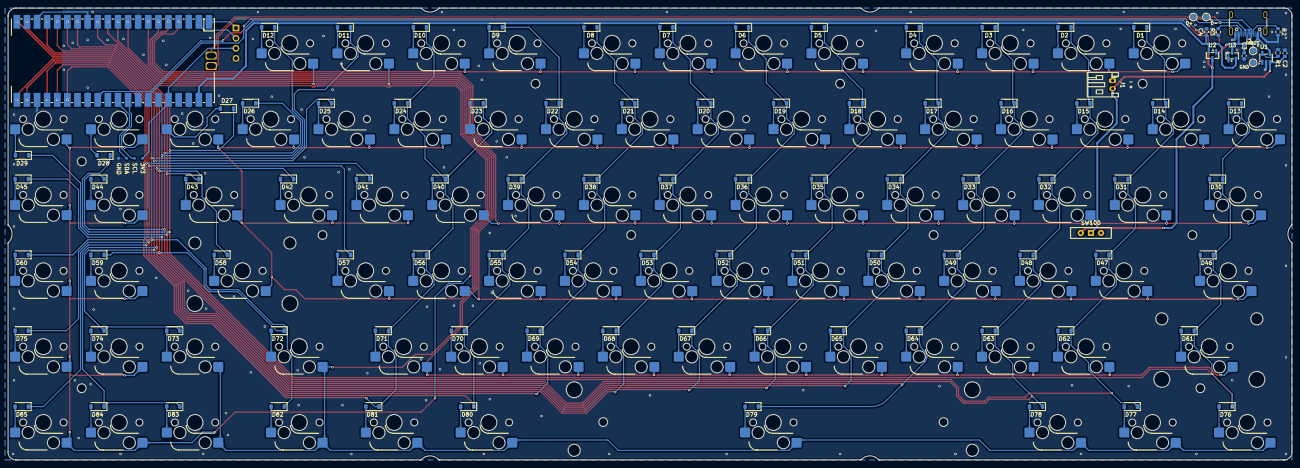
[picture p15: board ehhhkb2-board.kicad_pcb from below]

Board: 2 copper layers, 322.5 x 113.5 mm, 211 parts (106 on the bottom side), 121 nets.

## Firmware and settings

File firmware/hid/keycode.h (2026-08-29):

#ifndef EHHHKB2_KEYCODE_H
#define EHHHKB2_KEYCODE_H

#include <stdint.h>

#include "class/hid/hid.h"

// clang-format off
#define KC_NONE                       HID_KEY_NONE
#define KC_TRANS                      0x01
#define KC_FN                         0xf0
#define KC_FN2                        0xf1

// 16bit 仮想キーコードの割り当て: 0x0000-0x00FF=HID キーボード usage（キーボードレポートへ入れる）、0x0100-0x0FFF=ファームウェア内部のアクション（HID へは出さない）、0x1000-0x1FFF=Consumer Control usage（メディアキー。専用レポートで送る）
#define KC_ACTION_BASE                ((uint16_t)0x0100)
#define KC_BT1                        (KC_ACTION_BASE + 0x00)
#define KC_BT2                        (KC_ACTION_BASE + 0x01)
#define KC_BT3                        (KC_ACTION_BASE + 0x02)
#define KC_BT4                        (KC_ACTION_BASE + 0x03)
#define KC_BT5                        (KC_ACTION_BASE + 0x04)
#define KC_BT6                        (KC_ACTION_BASE + 0x05)
#define KC_PAIR                       (KC_ACTION_BASE + 0x10)
#define KC_BRST                       (KC_ACTION_BASE + 0x11)
#define KC_USB                        (KC_ACTION_BASE + 0x12)
#define KC_CFG                        (KC_ACTION_BASE + 0x13)

// Consumer Control（Usage Page 0x0C）。下位 12bit が usage そのもの。キーボードページの KC_MUTE / KC_VOLUME_UP / KC_VOLUME_DOWN とは別物で、メディアキーとして使えるのはこちら。
#define KC_MEDIA_BASE                 ((uint16_t)0x1000)
#define KC_MPLAY                      (KC_MEDIA_BASE + 0x00CD)
#define KC_MSTOP                      (KC_MEDIA_BASE + 0x00B7)
#define KC_MPREV                      (KC_MEDIA_BASE + 0x00B6)
#define KC_MNEXT                      (KC_MEDIA_BASE + 0x00B5)
#define KC_MMUTE                      (KC_MEDIA_BASE + 0x00E2)
#define KC_MVOLU                      (KC_MEDIA_BASE + 0x00E9)
#define KC_MVOLD                      (KC_MEDIA_BASE + 0x00EA)

#define KC_IS_ACTION(kc)              ((kc) >= KC_ACTION_BASE && \
                                       (kc) < KC_MEDIA_BASE)
#define KC_IS_MEDIA(kc)               ((kc) >= KC_MEDIA_BASE)
#define KC_MEDIA_USAGE(kc)            ((uint16_t)((kc) - KC_MEDIA_BASE))

// 真なら KC_MOD_BIT() で modifier ビットへ変換できる（0xE0..0xE7）
#define KC_IS_MODIFIER(kc)            ((kc) >= KC_LCTL && (kc) <= KC_RGUI)
#define KC_MOD_BIT(kc)                ((uint8_t)(1u << ((kc) - KC_LCTL)))

#define KC_A                          HID_KEY_A
#define KC_B                          HID_KEY_B
#define KC_C                          HID_KEY_C
#define KC_D                          HID_KEY_D
#define KC_E                          HID_KEY_E
#define KC_F                          HID_KEY_F
#define KC_G                          HID_KEY_G
#define KC_H                          HID_KEY_H
#define KC_I                          HID_KEY_I
#define KC_J                          HID_KEY_J
#define KC_K                          HID_KEY_K
#define KC_L                          HID_KEY_L
#define KC_M                          HID_KEY_M
#define KC_N                          HID_KEY_N
#define KC_O                          HID_KEY_O
#define KC_P                          HID_KEY_P
#define KC_Q                          HID_KEY_Q
#define KC_R                          HID_KEY_R
#define KC_S                          HID_KEY_S
#define KC_T                          HID_KEY_T
#define KC_U                          HID_KEY_U
#define KC_V                          HID_KEY_V
#define KC_W                          HID_KEY_W
#define KC_X                          HID_KEY_X
#define KC_Y                          HID_KEY_Y
#define KC_Z                          HID_KEY_Z
#define KC_1                          HID_KEY_1
#define KC_2                          HID_KEY_2
#define KC_3                          HID_KEY_3
#define KC_4                          HID_KEY_4
#define KC_5                          HID_KEY_5
#define KC_6                          HID_KEY_6
#define KC_7                          HID_KEY_7
#define KC_8                          HID_KEY_8
#define KC_9                          HID_KEY_9
#define KC_0                          HID_KEY_0
#define KC_ENTER                      HID_KEY_ENTER
#define KC_ESC                        HID_KEY_ESCAPE
#define KC_BSPC                       HID_KEY_BACKSPACE
#define KC_TAB                        HID_KEY_TAB
#define KC_SPACE                      HID_KEY_SPACE
#define KC_MIN                        HID_KEY_MINUS
#define KC_EQL                        HID_KEY_EQUAL
#define KC_LBRC                       HID_KEY_BRACKET_LEFT
#define KC_RBRC                       HID_KEY_BRACKET_RIGHT
#define KC_BSLS                       HID_KEY_BACKSLASH
#define KC_EUROPE_1                   HID_KEY_EUROPE_1
#define KC_SCLN                       HID_KEY_SEMICOLON
#define KC_QUOT                       HID_KEY_APOSTROPHE
#define KC_GRV                        HID_KEY_GRAVE
#define KC_COMM                       HID_KEY_COMMA
#define KC_DOT                        HID_KEY_PERIOD
#define KC_SLSH                       HID_KEY_SLASH
#define KC_CAPS                       HID_KEY_CAPS_LOCK
#define KC_F1                         HID_KEY_F1
#define KC_F2                         HID_KEY_F2
#define KC_F3                         HID_KEY_F3
#define KC_F4                         HID_KEY_F4
#define KC_F5                         HID_KEY_F5
#define KC_F6                         HID_KEY_F6
#define KC_F7                         HID_KEY_F7
#define KC_F8                         HID_KEY_F8
#define KC_F9                         HID_KEY_F9
#define KC_F10                        HID_KEY_F10
#define KC_F11                        HID_KEY_F11
#define KC_F12                        HID_KEY_F12
#define KC_PSCR                       HID_KEY_PRINT_SCREEN
#define KC_SCLK                       HID_KEY_SCROLL_LOCK
#define KC_PAUSE                      HID_KEY_PAUSE
#define KC_INS                        HID_KEY_INSERT
#define KC_HOME                       HID_KEY_HOME
#define KC_PGUP                       HID_KEY_PAGE_UP
#define KC_DEL                        HID_KEY_DELETE
#define KC_END                        HID_KEY_END
#define KC_PGDN                       HID_KEY_PAGE_DOWN
#define KC_RIGHT                      HID_KEY_ARROW_RIGHT
#define KC_LEFT                       HID_KEY_ARROW_LEFT
#define KC_DOWN                       HID_KEY_ARROW_DOWN
#define KC_UP                         HID_KEY_ARROW_UP
#define KC_NUM_LOCK                   HID_KEY_NUM_LOCK
#define KC_KEYPAD_DIVIDE              HID_KEY_KEYPAD_DIVIDE
#define KC_KEYPAD_MULTIPLY            HID_KEY_KEYPAD_MULTIPLY
#define KC_KEYPAD_SUBTRACT            HID_KEY_KEYPAD_SUBTRACT
#define KC_KEYPAD_ADD                 HID_KEY_KEYPAD_ADD
#define KC_KEYPAD_ENTER               HID_KEY_KEYPAD_ENTER
#define KC_KEYPAD_1                   HID_KEY_KEYPAD_1
#define KC_KEYPAD_2                   HID_KEY_KEYPAD_2
#define KC_KEYPAD_3                   HID_KEY_KEYPAD_3
#define KC_KEYPAD_4                   HID_KEY_KEYPAD_4
#define KC_KEYPAD_5                   HID_KEY_KEYPAD_5
#define KC_KEYPAD_6                   HID_KEY_KEYPAD_6
#define KC_KEYPAD_7                   HID_KEY_KEYPAD_7
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

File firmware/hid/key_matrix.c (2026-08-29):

#include "hid/key_matrix.h"

#include <string.h>

#include "class/hid/hid.h"
#include "keycode.h"
#include "pico/stdlib.h"

#define KEY_DEBOUNCE_TICKS 4

static layer_t current_layer = _BASE;

#define ____ KC_TRANS
#define _____ KC_TRANS
#define ______ KC_TRANS
#define _______ KC_TRANS

// clang-format off
const uint16_t keymap[LAYER_NUM][KEY_MATRIX_ROWS][KEY_MATRIX_COLS] = {
    [_BASE] = LAYOUT(
                  KC_F1,   KC_F2,   KC_F3,   KC_F4,    KC_F5,   KC_F6,   KC_F7,   KC_F8,     KC_F9,   KC_F10,   KC_F11,  KC_F12,                                  \
        KC_ESC,  KC_1,    KC_2,    KC_3,    KC_4,    KC_5,    KC_6,    KC_7,    KC_8,    KC_9,    KC_0,    KC_MIN,  KC_EQL,  KC_BSLS, KC_GRV,   KC_HOME, KC_END,  \
         KC_TAB,  KC_Q,    KC_W,    KC_E,    KC_R,    KC_T,    KC_Y,    KC_U,    KC_I,    KC_O,    KC_P,    KC_LBRC, KC_RBRC,     KC_BSPC,      KC_DEL,  KC_INS,  \
          KC_LCTL, KC_A,    KC_S,    KC_D,    KC_F,    KC_G,    KC_H,    KC_J,    KC_K,    KC_L,    KC_SCLN, KC_QUOT,          KC_ENTER,       KC_PSCR, KC_PGUP, \
          KC_LSFT,  KC_Z,    KC_X,    KC_C,    KC_V,    KC_B,    KC_N,    KC_M,    KC_COMM, KC_DOT,  KC_SLSH,            KC_RSFT,      KC_FN,   KC_UP,   KC_PGDN, \
        KC_LCTL,  KC_FN,  KC_LALT,                    KC_SPACE,                            KC_RGUI,  KC_RALT,   KC_RCTL,               KC_LEFT, KC_DOWN, KC_RIGHT
    ),
    [_FN] = LAYOUT(
                  _____,   _____,   _____,   _____,    _____,   _____,   _____,   _____,     _____,   ______,   ______,  ______,                                  \
        KC_FN2,  KC_F1,  KC_F2,   KC_F3,   KC_F4,   KC_F5,   KC_F6,   KC_F7,   KC_F8,   KC_F9,  KC_F10,    KC_F11,  KC_F12,   KC_KANJI3, KC_KANJI1,   _______,  ______, \
         KC_CAPS, ____,    ____,    ____,    ____,    ____,    ____,    ____,   KC_PSCR, KC_SCLK, KC_PAUSE, KC_UP,   _______,     _______,      _______,  ______, \
          _______, ____,    ____,    ____,    ____,    ____,    ____,    ____,    KC_HOME, KC_PGUP, KC_LEFT, KC_RIGHT,          KC_KEYPAD_ENTER, _______,  KC_MVOLU, \
          _______,  ____,    ____,    ____,    ____,    ____,    ____,    ____,    KC_END, KC_PGDN,  KC_DOWN,            _______,      _____,   KC_MSTOP, KC_MVOLD, \
        _______,  _____,  _______,                     _______,                            _______,  _______,   _______,              KC_MPREV, KC_MPLAY, KC_MNEXT
    ),
    [_FN2] = LAYOUT(
                  _____,   _____,   _____,   _____,    _____,   _____,   _____,   _____,     _____,   ______,   ______,  ______,                                  \
        KC_FN2,  KC_BT1,  KC_BT2,  KC_BT3,  KC_BT4,  KC_BT5,  KC_BT6,  KC_USB,  ____,    ____,    ____,    ______,  ______,  _______, ______,   _______, KC_CFG,  \
         ______,  ____,    ____,    ____,    ____,    ____,    ____,    ____,    ____,    ____,    ____,    _______, _______,     _______,      ______,  ______,  \
          _______, ____,    ____,    ____,    ____,    ____,    ____,    ____,    ____,    ____,    _______, _______,           _______,        _______, _______, \
          _______,  KC_BRST,    ____,    ____,    ____,    ____,    ____,    ____,    _______, ______,  _______,            _______,      _____,   _____,   _______, \
        _______,  _____,  _______,                     KC_PAIR,                            _______,  _______,   _______,               _______, _______, _______
    ),
};
// clang-format on

void key_matrix_init(key_matrix_t *matrix, const uint8_t *row_pins,
                     const uint8_t *col_pins) {
    memcpy(matrix->row_pins, row_pins, KEY_MATRIX_ROWS);
    memcpy(matrix->col_pins, col_pins, KEY_MATRIX_COLS);

    // row: 入力（プルアップ）、col: 出力（通常 HIGH、スキャン時に 1 本ずつ LOW）
    for (uint8_t i = 0; i < KEY_MATRIX_ROWS; ++i) {
        gpio_init(matrix->row_pins[i]);
        gpio_set_dir(matrix->row_pins[i], GPIO_IN);
        gpio_set_pulls(matrix->row_pins[i], true, false);
    }

    for (uint8_t j = 0; j < KEY_MATRIX_COLS; ++j) {
        gpio_init(matrix->col_pins[j]);
        gpio_set_dir(matrix->col_pins[j], GPIO_OUT);
        gpio_put(matrix->col_pins[j], true);
    }

    key_matrix_clear(matrix);
    current_layer = _BASE;
}

bool key_matrix_scan(key_matrix_t *matrix) {
    bool changed = false;

    for (uint8_t j = 0; j < KEY_MATRIX_COLS; ++j) {
        gpio_put(matrix->col_pins[j], false);
        sleep_us(2);  // 信号安定待ち

        for (uint8_t i = 0; i < KEY_MATRIX_ROWS; ++i) {
            const bool raw_pressed = !gpio_get(matrix->row_pins[i]);

            if (raw_pressed) {
                // 押下優先：押下は即確定し、離鍵は防止期間の満了を待つ。
                if (!matrix->key_states[i][j]) {
                    matrix->key_states[i][j] = true;
                    changed = true;
                }
                matrix->debounce_ticks[i][j] = KEY_DEBOUNCE_TICKS;
            } else if (matrix->key_states[i][j]) {
                if (matrix->debounce_ticks[i][j] > 0) {
                    matrix->debounce_ticks[i][j]--;
                } else {
                    matrix->key_states[i][j] = false;
                    changed = true;
                }
            }
        }

        gpio_put(matrix->col_pins[j], true);
    }

    return changed;
}

static layer_t resolve_layer(const key_matrix_t *matrix) {
    bool fn_held = false;
    for (uint8_t i = 0; i < KEY_MATRIX_ROWS; ++i)
        for (uint8_t j = 0; j < KEY_MATRIX_COLS; ++j)
            if (matrix->key_states[i][j] && keymap[_BASE][i][j] == KC_FN)
                fn_held = true;
    if (!fn_held) return _BASE;
    for (uint8_t i = 0; i < KEY_MATRIX_ROWS; ++i)
        for (uint8_t j = 0; j < KEY_MATRIX_COLS; ++j)
            if (matrix->key_states[i][j] && keymap[_FN][i][j] == KC_FN2)
                return _FN2;
    return _FN;
}
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
